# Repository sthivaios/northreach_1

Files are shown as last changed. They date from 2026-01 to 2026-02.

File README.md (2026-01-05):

# NorthReach 1

## Introduction

NorthReach 1 is a wired USB remote controller, to aid during presentations, particularly
on touchscreen interactive whiteboards.

Apart from basic features that other commercially available presenter remotes have, NorthReach
includes buttons for controlling Windows computers by default, such as a separate button for closing
the focused window, or a button to bring up Task Manager in the event that some application freezes.

The firmware is written in C, with the Espressif ESP-IDF framework. Through the `menuconfig` utility,
the board can be reconfigured to assign different actions to any button, for example to make the remote
compatible with MacOS.

Additionally, under the `hardware/` directory, the KiCad project for the PCB is available, as well
as the 3D printed enclosure inside `enclosure/`.

**The firmware and the PCB is only designed for ESP-S3 modules which natively support USB.**

In the future, there will also be a wireless version of NorthReach, possibly based on a Nordic nRF SoC.
However, for now, I'm focusing on the wired version.

## Contributing

You are more than welcome to contribute to the project, by forking then creating a pull request.
If you are an end user, feel free to request new features or report a bug by creating an issue
on this repository on GitHub.

If you are actually contributing code to the project, make sure that you understand the license terms.

## Licensing
This project contains multiple components under different licenses.
See [LICENSE](LICENSE) for more details.

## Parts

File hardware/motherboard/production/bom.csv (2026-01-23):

Designator | Footprint | Quantity | Value | LCSC Part #
C1 | 0805 | 1 | 1uF | C28323
C2, C5 | 0805 | 2 | 10uF | C15850
C3, C4 | 0805 | 2 | 0.1uF | C28233
J1 | USB_C_Receptacle_Amphenol_12401610E4-2A | 1 | USB_C_Receptacle | C5119948
J2, J4 | PinHeader_1x03_P2.54mm_Vertical | 2 | Conn_01x03_Pin
J3 | Hirose_FH12-20S-0.5SH_1x20-1MP_P0.50mm_Horizontal | 1 | Conn_01x20 | C596730
R1, R2 | 0805 | 2 | 5.1k | C84375
R3, R4 | 0805 | 2 | 10k | C84376
SW1, SW2 | SW_PUSH_6mm_H4.3mm | 2 | SW_Push
U1 | Texas_RGW0020A_VQFN-20-1EP_5x5mm_P0.65mm_EP3.15x3.15mm_ThermalVias | 1 | TPS7A4701xRGW | C90084
U2 | ESP32-S2-MINI-1U | 1 | ESP32-S3-MINI-1U | C2980299
U3 | SOT-23-6 | 1 | USBLC6-2SC6 | C7519

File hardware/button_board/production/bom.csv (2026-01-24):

Designator | Footprint | Quantity | Value | LCSC Part #
J1 | Hirose_FH12-20S-0.5SH_1x20-1MP_P0.50mm_Horizontal | 1 | Conn_01x20
SW1 | SW_BUTTON_SoftTactile | 1 | Left
SW10 | SW_BUTTON_SoftTactile | 1 | Vol_Up
SW11 | SW_BUTTON_SoftTactile | 1 | Vol_Down
SW2 | SW_BUTTON_SoftTactile | 1 | Right
SW3 | SW_BUTTON_SoftTactile | 1 | Up
SW4 | SW_BUTTON_SoftTactile | 1 | Down
SW5 | SW_BUTTON_SoftTactile | 1 | Return
SW6 | SW_BUTTON_SoftTactile | 1 | Fn_1
SW7 | SW_BUTTON_SoftTactile | 1 | Fn_2
SW8 | SW_BUTTON_SoftTactile | 1 | Fn_3
SW9 | SW_BUTTON_SoftTactile | 1 | Fn_4

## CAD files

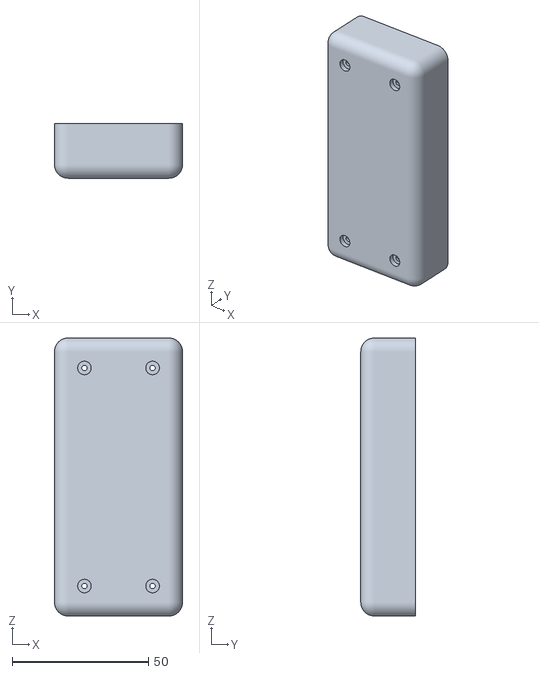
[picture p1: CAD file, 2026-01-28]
enclosure/v4/exports/northreach_1_v4_NorthReach 1 v23_MainBody_1_MainBody.stl
47.0 x 20.0 x 102.0

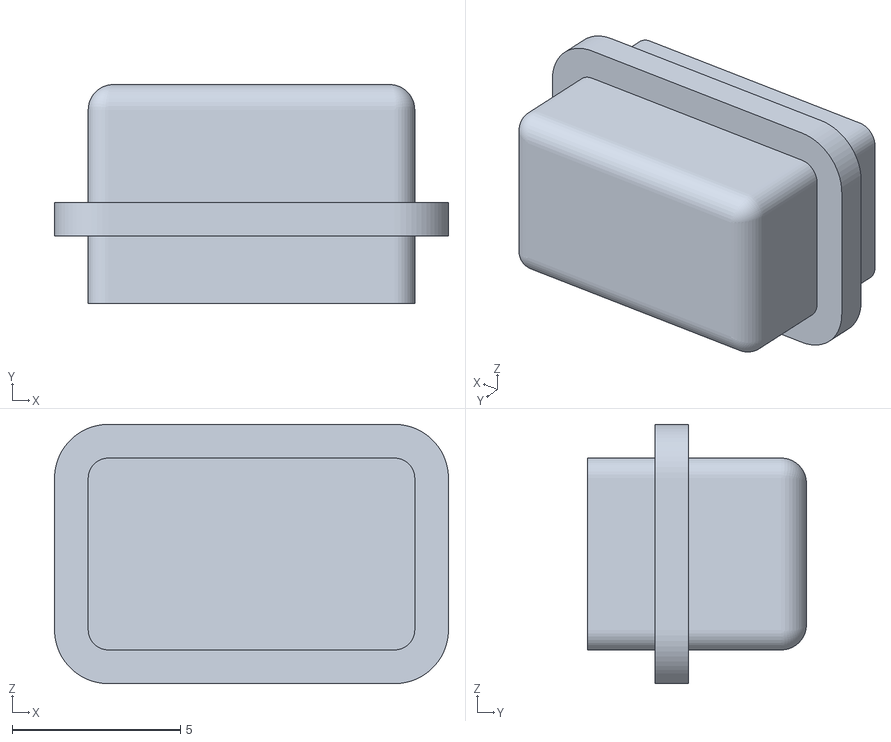
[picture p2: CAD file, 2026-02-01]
enclosure/v4/exports/rectangle_button_single.stl
11.7 x 6.50 x 7.70

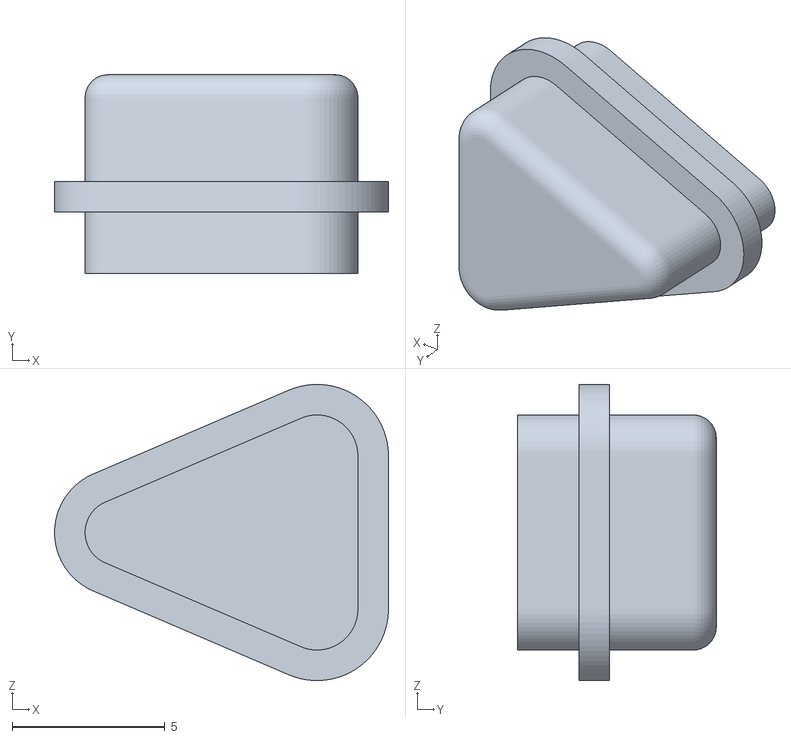
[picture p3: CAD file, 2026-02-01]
enclosure/v4/exports/triangle_button_single.stl
10.9 x 6.50 x 9.69

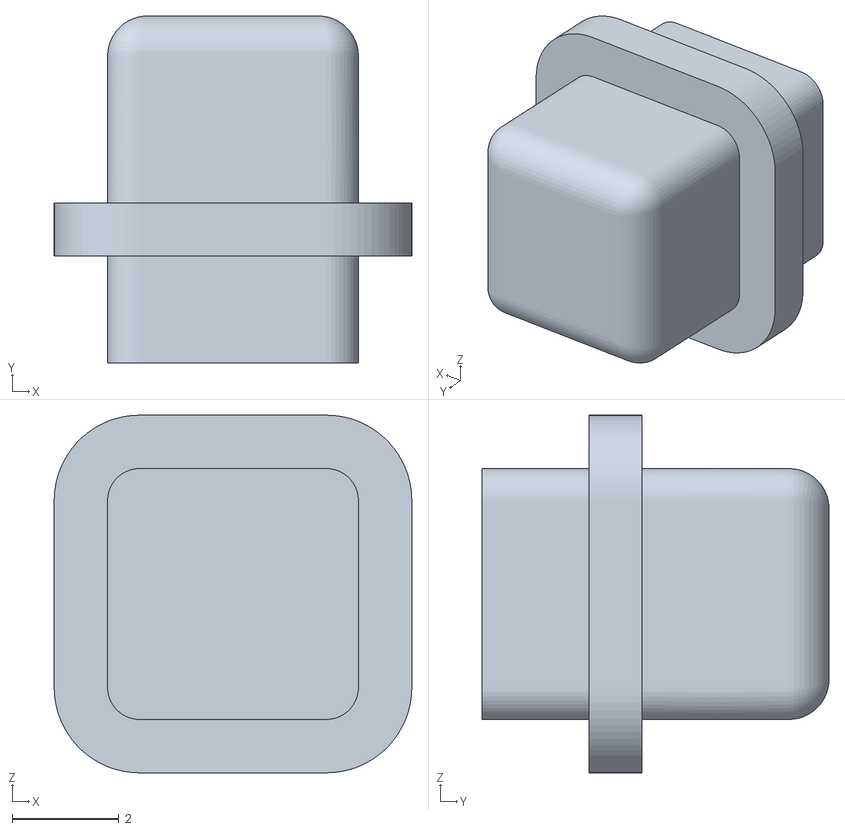
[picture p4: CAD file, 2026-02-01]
enclosure/v4/exports/square_button_single.stl
6.70 x 6.50 x 6.70

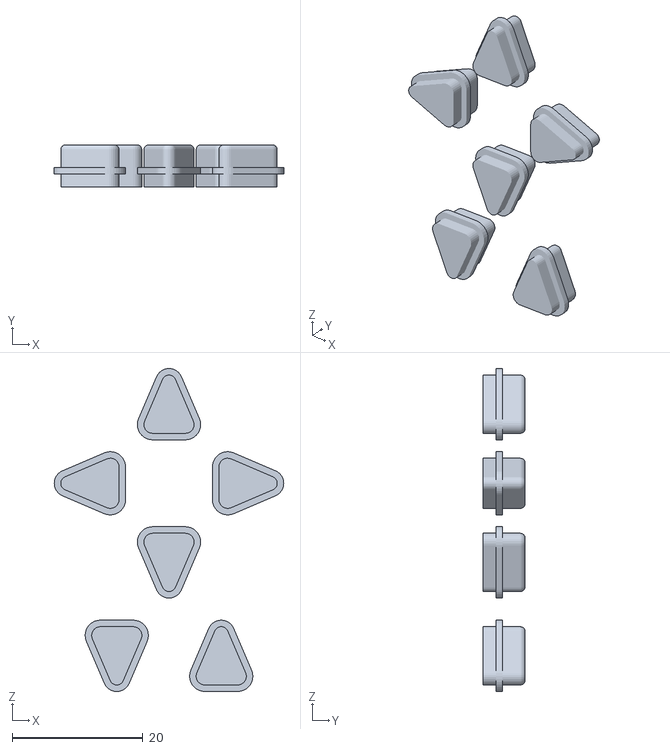
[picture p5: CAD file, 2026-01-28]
enclosure/v4/exports/northreach_1_v4_NorthReach 1 v23_Buttons_1_TriangleButton_1_TriangleButton.stl
35.2 x 6.50 x 49.5

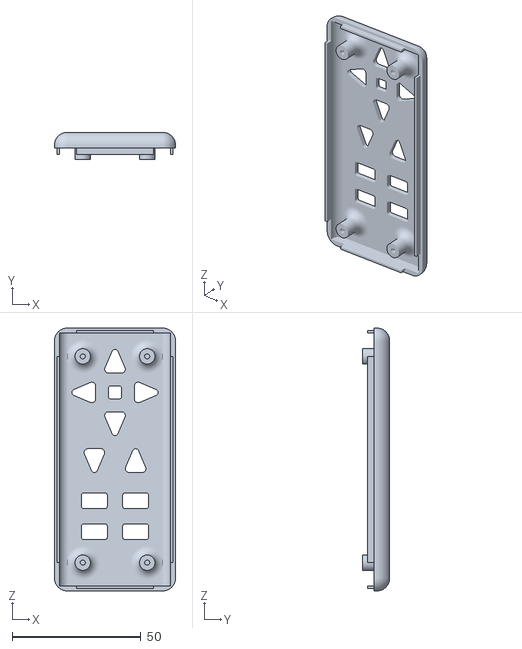
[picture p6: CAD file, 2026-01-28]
enclosure/v4/exports/northreach_1_v4_NorthReach 1 v23_TopCover_1_TopCover.stl
47.0 x 10.6 x 102.0

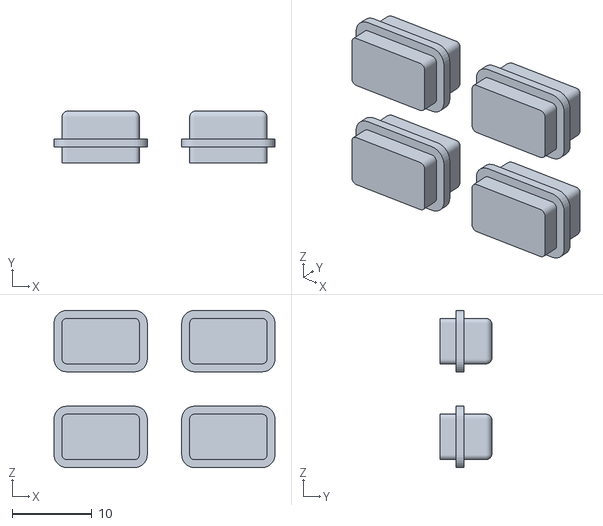
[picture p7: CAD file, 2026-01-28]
enclosure/v4/exports/northreach_1_v4_NorthReach 1 v23_Buttons_1_RectangleButton_1_RectangleButton.stl
27.7 x 6.50 x 19.7

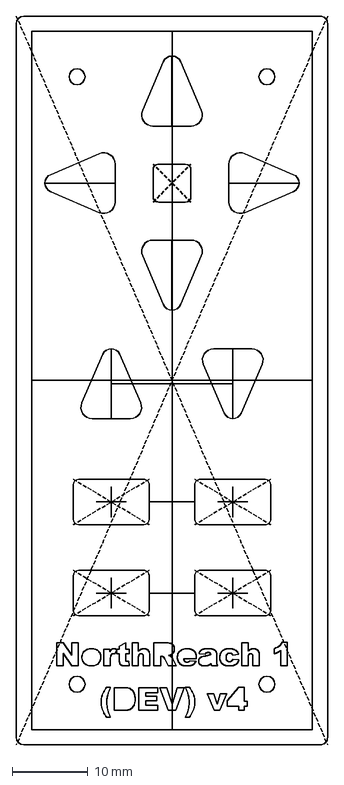
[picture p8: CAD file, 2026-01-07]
enclosure/v4/exports/KiCad_PCB_Reference.dxf
41.0 x 96.0 mm

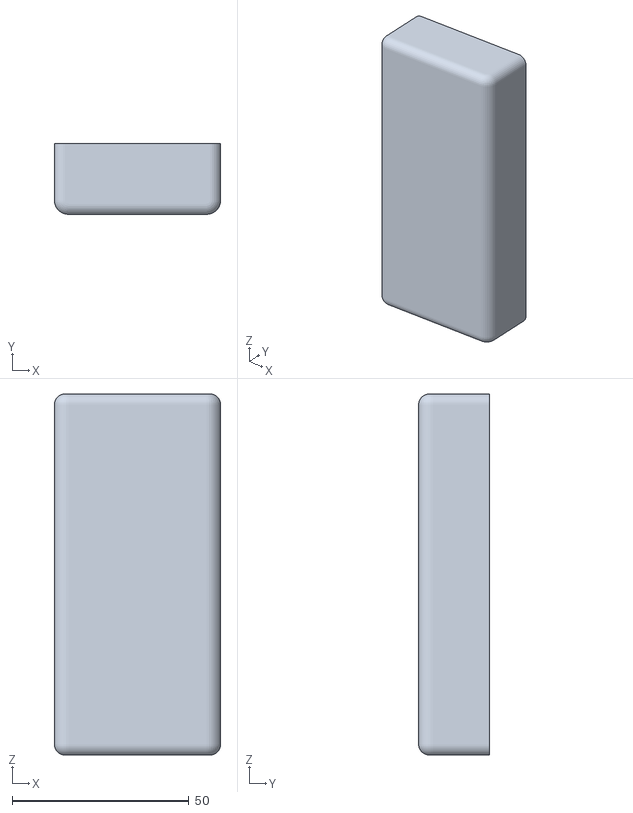
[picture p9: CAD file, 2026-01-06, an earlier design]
enclosure/v1/exports/northreach_1_v1_main-body.stl
47.0 x 20.0 x 102.0

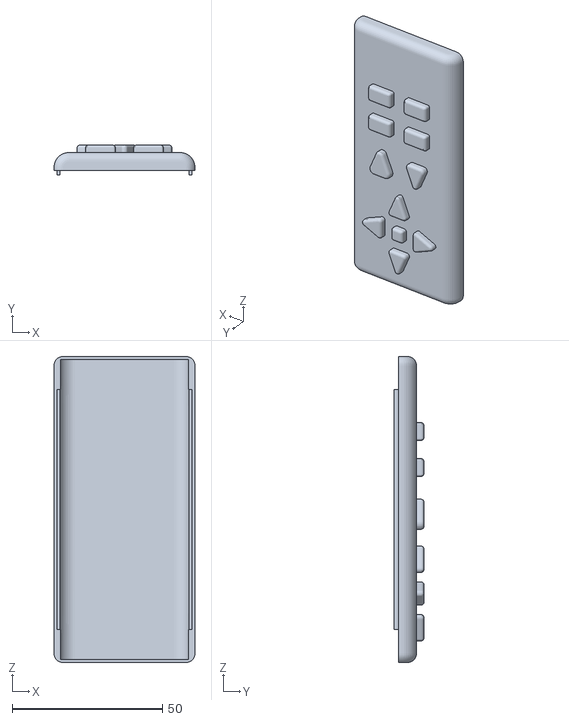
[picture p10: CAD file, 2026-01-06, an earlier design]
enclosure/v1/exports/northreach_1_v1_top-cover.stl
47.0 x 10.0 x 102.0

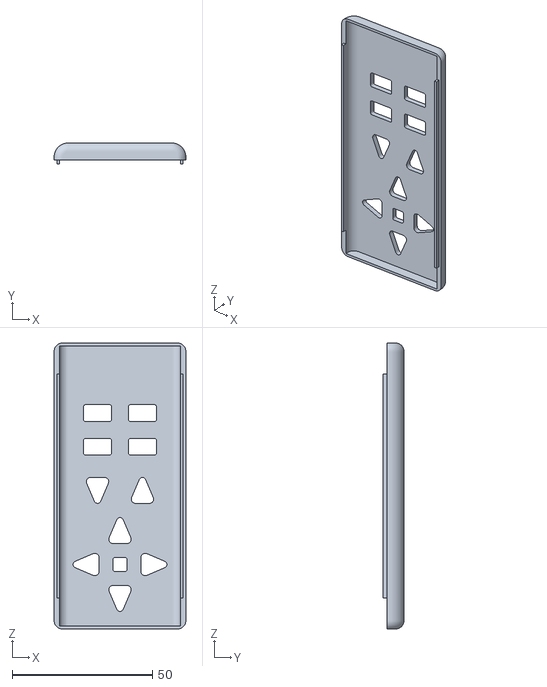
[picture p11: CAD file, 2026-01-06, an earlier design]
enclosure/v2/exports/northreach_1_v2_TopCover.stl
47.0 x 7.50 x 102.0

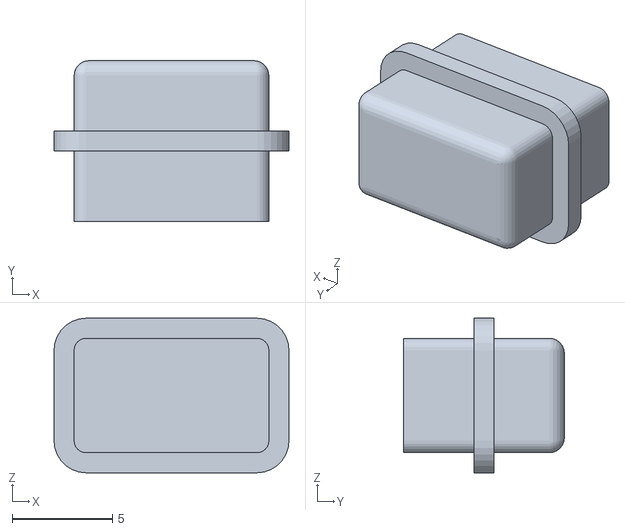
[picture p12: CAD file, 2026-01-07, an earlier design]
enclosure/v3/exports/northreach_1_v3_NorthReach 1 v11_RectangleButton_3_RectangleButton.stl
11.7 x 8.00 x 7.70

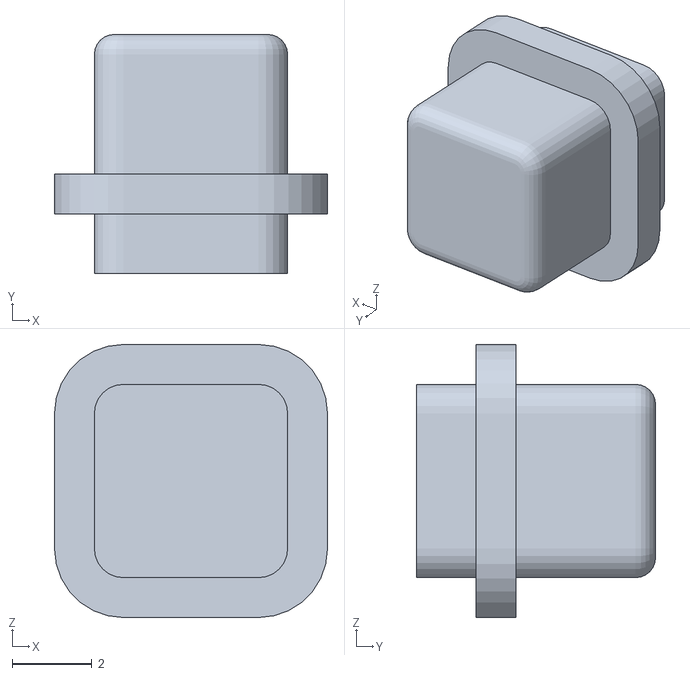
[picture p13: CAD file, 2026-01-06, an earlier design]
enclosure/v2/exports/northreach_1_v2_SquareButton.stl
6.85 x 6.00 x 6.85

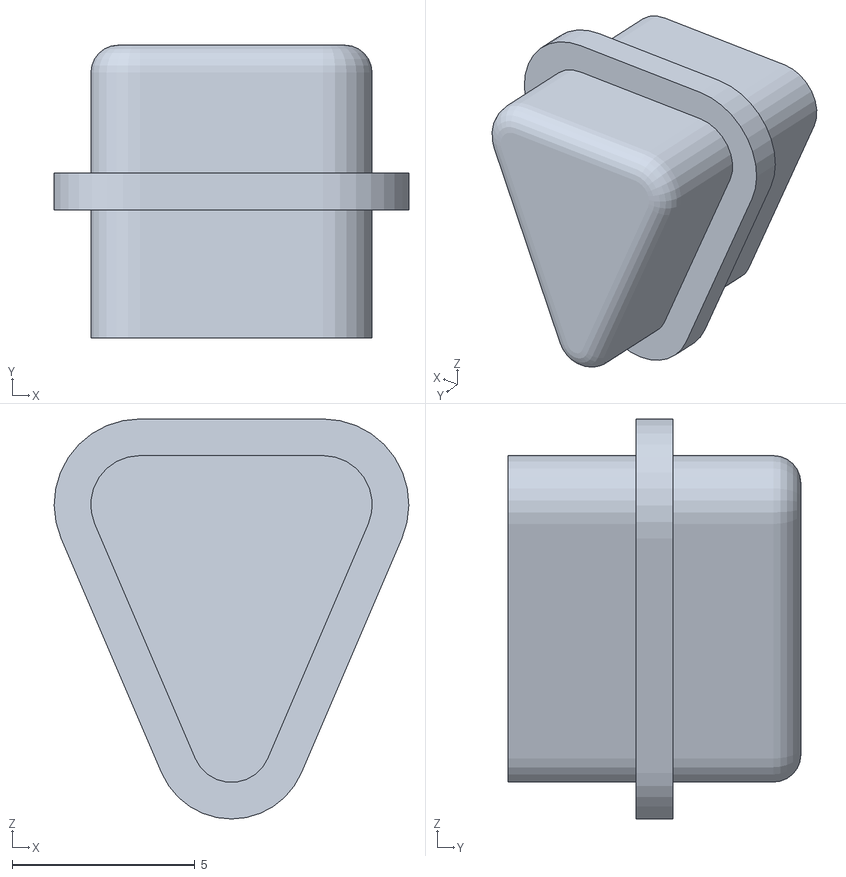
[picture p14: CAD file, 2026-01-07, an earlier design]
enclosure/v3/exports/northreach_1_v3_NorthReach 1 v11_TriangleButton_4_TriangleButton.stl
9.69 x 8.00 x 10.9

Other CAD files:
enclosure/v4/exports/northreach_1_v4_NorthReach 1 v23_Buttons_1_SquareButton_1_SquareButton.stl
enclosure/v2/exports/northreach_1_v2_MainBody.stl
enclosure/v3/exports/northreach_1_v3_NorthReach 1 v11_MainBody_1_MainBody.stl
enclosure/v2/exports/northreach_1_v2_RectangleButton.stl
enclosure/v1/northreach_1_v1.f3d
enclosure/v2/exports/northreach_1_v2_TriangleButton.stl
enclosure/v2/northreach_1_v2.f3d
enclosure/v3/exports/northreach_1_v3_NorthReach 1 v11_RectangleButton_1_RectangleButton.stl
enclosure/v3/exports/northreach_1_v3_NorthReach 1 v11_RectangleButton_2_RectangleButton.stl
enclosure/v3/exports/northreach_1_v3_NorthReach 1 v11_RectangleButton_4_RectangleButton.stl
enclosure/v3/exports/northreach_1_v3_NorthReach 1 v11_SquareButton_1_SquareButton.stl
enclosure/v3/exports/northreach_1_v3_NorthReach 1 v11_TopCover_1_TopCover.stl
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

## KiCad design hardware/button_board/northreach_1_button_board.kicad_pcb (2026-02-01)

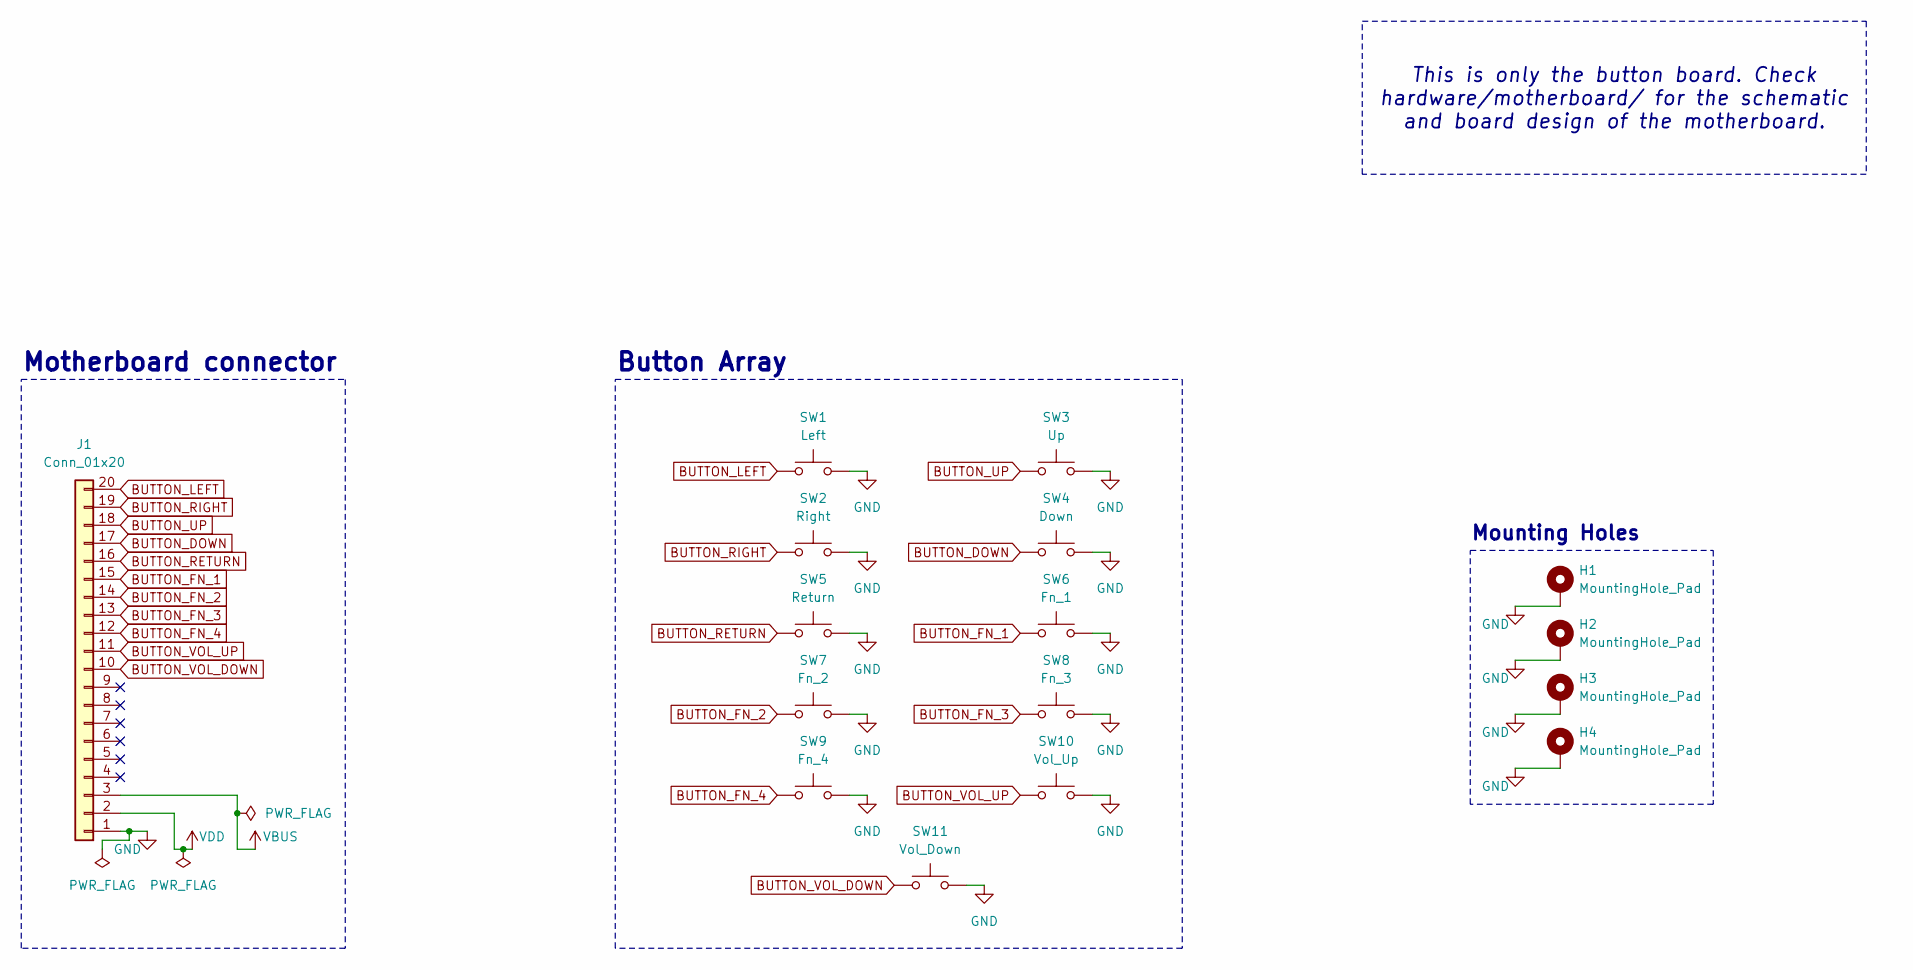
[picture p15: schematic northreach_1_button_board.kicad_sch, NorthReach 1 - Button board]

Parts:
H1, H2, H3, H4: MountingHole_Pad; MountingHole_2.2mm_M2_Pad
J1: Conn_01x20; Hirose_FH12-20S-0.5SH_1x20-1MP_P0.50mm_Horizontal; LCSC C596730
SW1: Left; SW_BUTTON_SoftTactile
SW2: Right; SW_BUTTON_SoftTactile
SW3: Up; SW_BUTTON_SoftTactile
SW4: Down; SW_BUTTON_SoftTactile
SW5: Return; SW_BUTTON_SoftTactile
SW6: Fn_1; SW_BUTTON_SoftTactile
SW7: Fn_2; SW_BUTTON_SoftTactile
SW8: Fn_3; SW_BUTTON_SoftTactile
SW9: Fn_4; SW_BUTTON_SoftTactile
SW10: Vol_Up; SW_BUTTON_SoftTactile
SW11: Vol_Down; SW_BUTTON_SoftTactile

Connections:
BUTTON_DOWN: J1.17, SW4.1
BUTTON_FN_1: J1.15, SW6.1
BUTTON_FN_2: J1.14, SW7.1
BUTTON_FN_3: J1.13, SW8.1
BUTTON_FN_4: J1.12, SW9.1
BUTTON_LEFT: J1.20, SW1.1
BUTTON_RETURN: J1.16, SW5.1
BUTTON_RIGHT: J1.19, SW2.1
BUTTON_UP: J1.18, SW3.1
BUTTON_VOL_DOWN: J1.10, SW11.1
BUTTON_VOL_UP: J1.11, SW10.1
GND: H1.1, H2.1, H3.1, H4.1, J1.1, SW1.2, SW2.2, SW3.2, SW4.2, SW5.2, SW6.2, SW7.2, SW8.2, SW9.2, SW10.2, SW11.2
VBUS: J1.3
VDD: J1.2

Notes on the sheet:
Motherboard connector
Mounting Holes
Button Array
This is only the button board. Check hardware/motherboard/ for the schematic and board design of the motherboard.

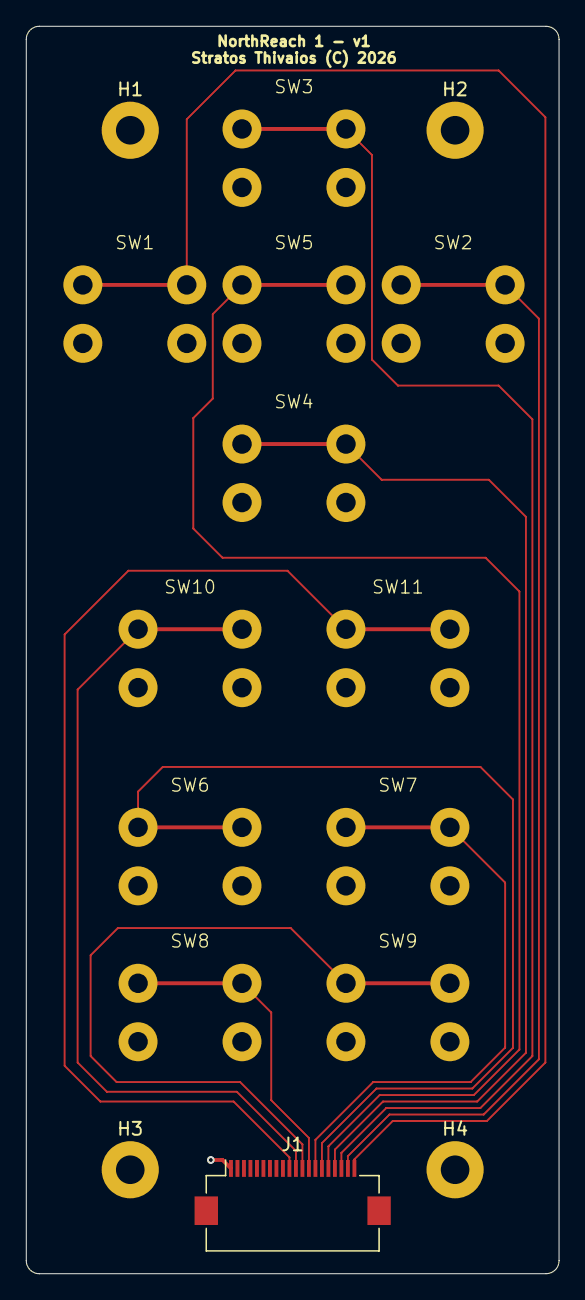
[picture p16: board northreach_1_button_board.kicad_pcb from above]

Board: 2 copper layers, 41.0 x 96.0 mm, 16 parts (0 on the bottom side), 12 nets.

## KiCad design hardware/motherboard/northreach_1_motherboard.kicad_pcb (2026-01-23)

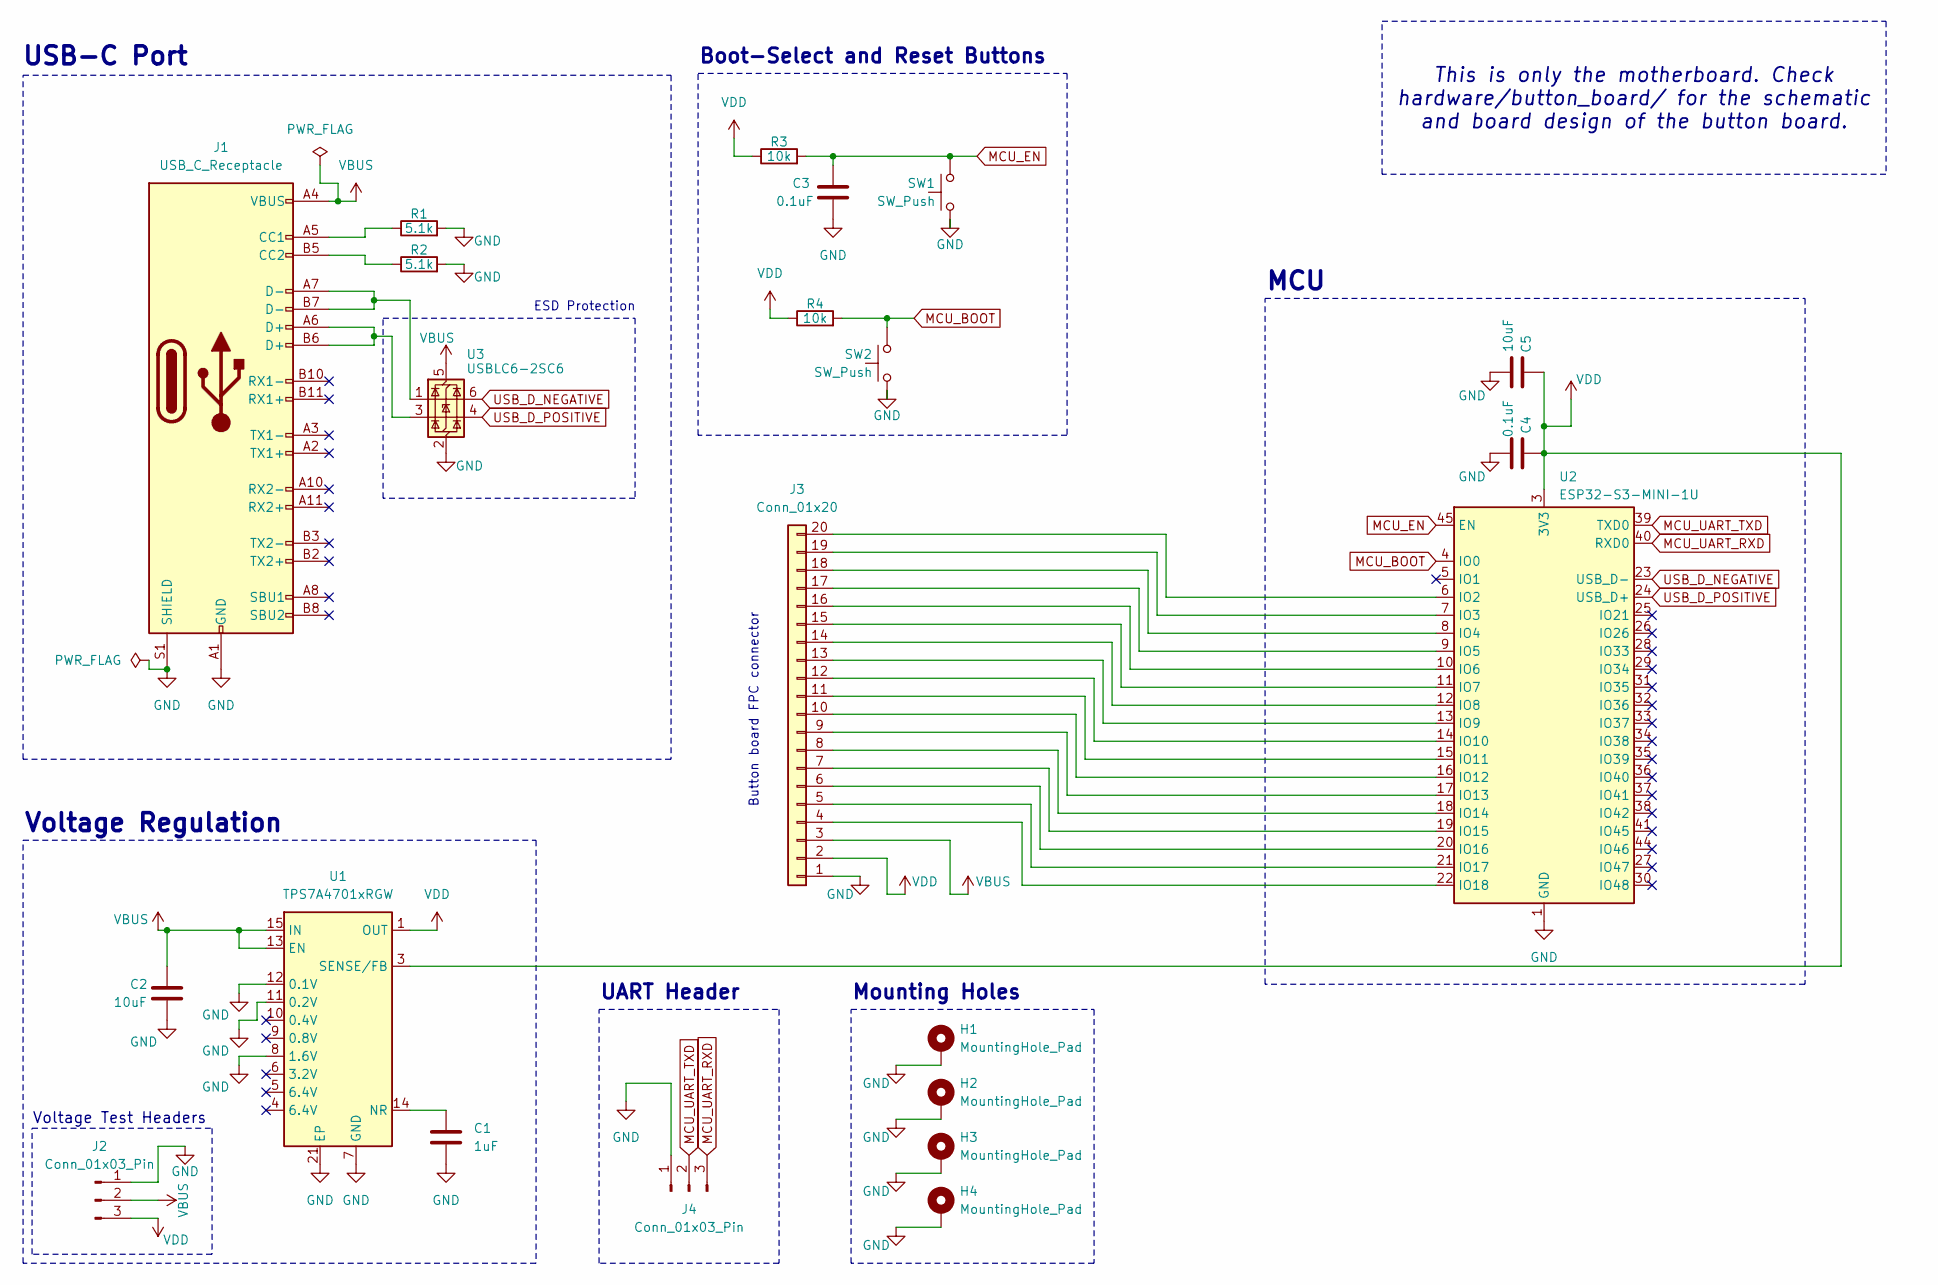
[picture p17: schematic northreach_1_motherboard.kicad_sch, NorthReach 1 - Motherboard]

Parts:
C1: 1uF; C_0805_2012Metric; LCSC C28323
C2, C5: 10uF; C_0805_2012Metric; LCSC C15850
C3, C4: 0.1uF; C_0805_2012Metric; LCSC C28233
H1, H2, H3, H4: MountingHole_Pad; MountingHole_2.2mm_M2_Pad
J1: USB_C_Receptacle; USB_C_Receptacle_Amphenol_12401610E4-2A; LCSC C5119948
J2, J4: Conn_01x03_Pin; PinHeader_1x03_P2.54mm_Vertical
J3: Conn_01x20; Hirose_FH12-20S-0.5SH_1x20-1MP_P0.50mm_Horizontal; LCSC C596730
R1, R2: 5.1k; R_0805_2012Metric; LCSC C84375
R3, R4: 10k; R_0805_2012Metric; LCSC C84376
SW1, SW2: SW_Push; SW_PUSH_6mm_H4.3mm
U1: TPS7A4701xRGW; Texas_RGW0020A_VQFN-20-1EP_5x5mm_P0.65mm_EP3.15x3.15mm_Ther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; LCSC C90084
U2: ESP32-S3-MINI-1U; ESP32-S2-MINI-1U; LCSC C2980299
U3: USBLC6-2SC6; SOT-23-6; LCSC C7519

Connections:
GND: C1.1, C2.1, C3.1, C4.1, C5.1, H1.1, H2.1, H3.1, H4.1, J1.A1 (GND), J1.A12 (GND), J1.B1 (GND), J1.B12 (GND), J1.S1 (SHIELD), J2.1, J3.1, J4.1, R1.2, R2.2, SW1.1, SW2.1, U1.7 (GND), U1.8 (1.6V), U1.11 (0.2V), U1.12 (0.1V), U1.21 (EP), U2.1 (GND), U2.2 (GND), U2.42 (GND), U2.43 (GND), U2.46 (GND), U2.47 (GND), U2.48 (GND), U2.49 (GND), U2.50 (GND), U2.51 (GND), U2.52 (GND), U2.53 (GND), U2.54 (GND), U2.55 (GND), U2.56 (GND), U2.57 (GND), U2.58 (GND), U2.59 (GND), U2.60 (GND), U2.61 (GND), U2.62 (GND), U2.63 (GND), U2.64 (GND), U2.65 (GND), U3.2 (GND)
MCU_BOOT: R4.2, SW2.2, U2.4 (IO0)
MCU_EN: C3.2, R3.2, SW1.2, U2.45 (EN)
MCU_UART_RXD: J4.3, U2.40 (RXD0)
MCU_UART_TXD: J4.2, U2.39 (TXD0)
unnamed: J1.A5 (CC1), R1.1
unnamed: J1.B5 (CC2), R2.1
unnamed: J1.A6 (D+), J1.B6 (D+), U3.3 (I/O2)
unnamed: J1.A7 (D-), J1.B7 (D-), U3.1 (I/O1)
unnamed: J3.4, U2.22 (IO18)
unnamed: J3.5, U2.21 (IO17)
unnamed: J3.6, U2.20 (IO16)
unnamed: J3.7, U2.19 (IO15)
unnamed: J3.8, U2.18 (IO14)
unnamed: J3.9, U2.17 (IO13)
unnamed: J3.10, U2.16 (IO12)
unnamed: J3.11, U2.15 (IO11)
unnamed: J3.12, U2.14 (IO10)
unnamed: J3.13, U2.13 (IO9)
unnamed: J3.14, U2.12 (IO8)
unnamed: J3.15, U2.11 (IO7)
unnamed: J3.16, U2.10 (IO6)
unnamed: J3.17, U2.9 (IO5)
unnamed: J3.18, U2.8 (IO4)
unnamed: J3.19, U2.7 (IO3)
unnamed: J3.20, U2.6 (IO2)
unnamed: C1.2, U1.14 (NR)
USB_D_NEGATIVE: U2.23 (USB_D-), U3.6 (I/O1)
USB_D_POSITIVE: U2.24 (USB_D+), U3.4 (I/O2)
VBUS: C2.2, J1.A4 (VBUS), J1.A9 (VBUS), J1.B4 (VBUS), J1.B9 (VBUS), J2.2, J3.3, U1.13 (EN), U1.15 (IN), U1.16 (IN), U3.5 (VBUS)
VDD: C4.2, C5.2, J2.3, J3.2, R3.1, R4.1, U1.1 (OUT), U1.3 (SENSE/FB), U1.20 (OUT), U2.3 (3V3)

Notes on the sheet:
Voltage Regulation
Voltage Test Headers
Mounting Holes
UART Header
Boot-Select and Reset Buttons
Button board FPC connector
MCU
ESD Protection
USB-C Port
This is only the motherboard. Check hardware/button_board/ for the schematic and board design of the button board.

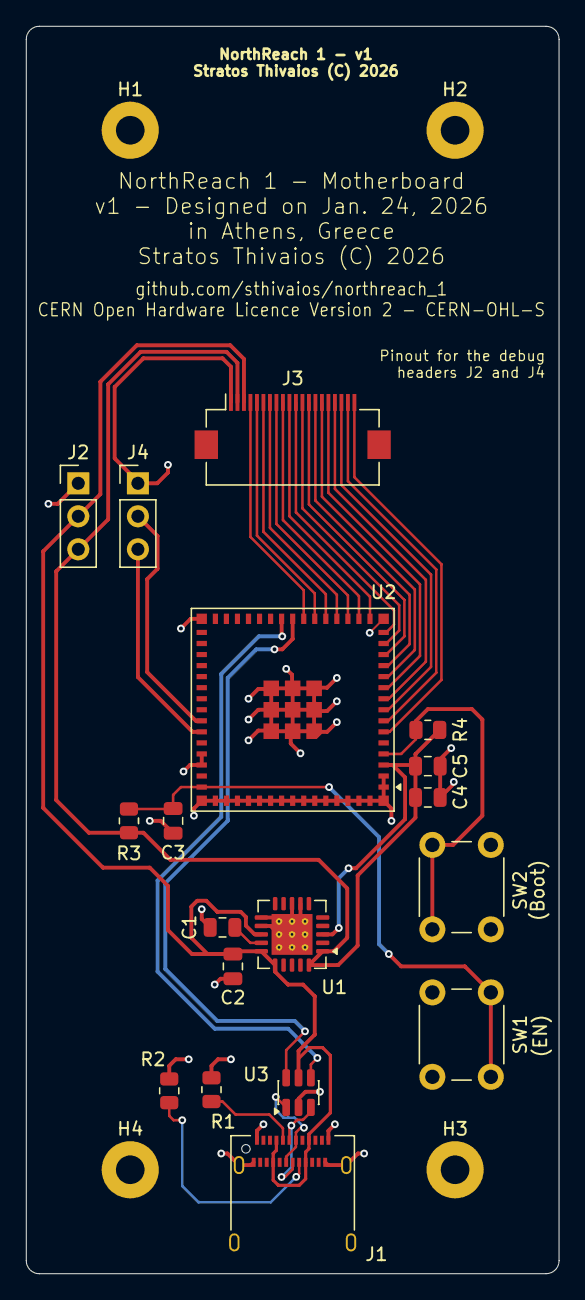
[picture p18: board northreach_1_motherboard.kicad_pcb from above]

Board: 2 copper layers, 41.0 x 96.0 mm, 22 parts (0 on the bottom side), 31 nets.

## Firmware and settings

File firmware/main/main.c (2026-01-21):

// Copyright 2026 Stratos Thivaios
//
// Licensed under the Apache License, Version 2.0 (the "License");
// you may not use this file except in compliance with the License.
// You may obtain a copy of the License at
//
//     http://www.apache.org/licenses/LICENSE-2.0
//
// Unless required by applicable law or agreed to in writing, software
// distributed under the License is distributed on an "AS IS" BASIS,
// WITHOUT WARRANTIES OR CONDITIONS OF ANY KIND, either express or implied.
// See the License for the specific language governing permissions and
// limitations under the License.

#include "buttons.h"
#include "hid.h"

#include <task.h>

void app_main(void) {

  xTaskCreate(buttonTask, "button_task", 8192, NULL, 10, NULL);
  xTaskCreate(hid_task, "hid_task", 8192, NULL, 5, NULL);
}

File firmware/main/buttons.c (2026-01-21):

// Copyright 2026 Stratos Thivaios
//
// Licensed under the Apache License, Version 2.0 (the "License");
// you may not use this file except in compliance with the License.
// You may obtain a copy of the License at
//
//     http://www.apache.org/licenses/LICENSE-2.0
//
// Unless required by applicable law or agreed to in writing, software
// distributed under the License is distributed on an "AS IS" BASIS,
// WITHOUT WARRANTIES OR CONDITIONS OF ANY KIND, either express or implied.
// See the License for the specific language governing permissions and
// limitations under the License.

#include "buttons.h"

#include "freertos/FreeRTOS.h"
#include "freertos/queue.h"

#include "button_gpio.h"
#include "button_types.h"
#include "esp_log.h"
#include "iot_button.h"

static const char *TAG = "button_task";

QueueHandle_t xButtonEventQueue;
static button_handle_t button_handles_array[11];

// disgusting stupid array for getting a string from the enums to print to the
// log
static const char *button_names[11] = {
    [BTN_UP] = "UP",
    [BTN_DOWN] = "DOWN",
    [BTN_LEFT] = "LEFT",
    [BTN_RIGHT] = "RIGHT",
    [BTN_ENTER] = "ENTER",
    [BTN_VOL_UP] = "VOL_UP",
    [BTN_VOL_DOWN] = "VOL_DOWN",
    [BTN_F1] = "F1",
    [BTN_F2] = "F2",
    [BTN_F3] = "F3",
    [BTN_F4] = "F4",
};

BaseType_t xButtonQueueReceive(button_id_enum *ButtonID,
                               const TickType_t xTicksToWait) {
  if (!xButtonEventQueue || ButtonID == NULL) {
    return pdFAIL;
  }
  return xQueueReceive(xButtonEventQueue, ButtonID, xTicksToWait);
}

BaseType_t xButtonQueueSend(button_id_enum ButtonID,
                            const TickType_t xTicksToWait) {
  if (!xButtonEventQueue) {
    return pdFAIL;
  }
  return xQueueSend(xButtonEventQueue, &ButtonID, xTicksToWait);
}

void button_single_click_cb(void *arg, void *usr_data) {
  const button_id_enum btn_id = (button_id_enum)(intptr_t)usr_data;
  ESP_LOGI(TAG, "Click event from button: %s", button_names[btn_id]);
  xButtonQueueSend(btn_id, portMAX_DELAY);
}

void buttons_init() {

  int i_pin = 2;
  int i_array = 0;

  while (i_pin <= 12) {
    const button_config_t btn_cfg = {0};
    const button_gpio_config_t btn_gpio_cfg = {
        .gpio_num = i_pin,
        .active_level = 0,
    };
    button_handle_t gpio_btn = NULL;
    ESP_ERROR_CHECK(
        iot_button_new_gpio_device(&btn_cfg, &btn_gpio_cfg, &gpio_btn));
    if (NULL == gpio_btn) {
      ESP_LOGE(TAG, "Button [ %d ] create failed", i_pin);
      abort();
    }

    button_handles_array[i_array] = gpio_btn;

    ESP_LOGI(TAG, "Button [ %d ] configured", i_pin);

    i_pin++;
    i_array++;
  }

  const button_id_enum btn_ids[] = {
      BTN_LEFT, BTN_RIGHT, BTN_UP, BTN_DOWN,   BTN_ENTER,   BTN_F1,
      BTN_F2,   BTN_F3,    BTN_F4, BTN_VOL_UP, BTN_VOL_DOWN};

  for (int i = 0; i <= 10; i++) {
    ESP_LOGI(TAG, "Registering: Button array index: %d - %s", i,
             button_names[btn_ids[i]]);
    if (i <= 4 || i >= 9) {
      ESP_ERROR_CHECK(iot_button_register_cb(
          button_handles_array[i], BUTTON_PRESS_DOWN, NULL,
          button_single_click_cb, (void *)(intptr_t)btn_ids[i]));
      ESP_ERROR_CHECK(iot_button_register_cb(
          button_handles_array[i], BUTTON_LONG_PRESS_HOLD, NULL,
          button_single_click_cb, (void *)(intptr_t)btn_ids[i]));
      // ESP_LOGI(TAG, "Registered callbacks for button [ %d ]", i);
    } else {
      ESP_ERROR_CHECK(iot_button_register_cb(
          button_handles_array[i], BUTTON_LONG_PRESS_START, NULL,
          button_single_click_cb, (void *)(intptr_t)btn_ids[i]));
      // ESP_LOGI(TAG, "Registered long press callbacks for button [ %d ]", i);
    }
  }
}

void buttonTask(void *pvParameters) {

  buttons_init();

  xButtonEventQueue = xQueueCreate(50, sizeof(button_id_enum));
  if (xButtonEventQueue == NULL) {
    ESP_LOGE(TAG, "The button event queue was not created successfully! This "
                  "is a fatal error. Aborting!");
    abort();
  }

  ESP_LOGW(TAG, "Buttons configured successfully in the button task. The task "
                "will now self delete.");
  vTaskDelete(NULL);
}

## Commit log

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2026-01-06 schematic: usb-c port section
    [northreach_1.kicad_sch]
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2026-01-06 schematic: add voltage regulator
    [northreach_1.kicad_sch]
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2026-01-06 enclosure: stl exports of v1
    [northreach_1_v1_main-body.stl, northreach_1_v1_top-cover.stl]
2026-01-06 enclosure: v1 - update fillets and stuff
    [northreach_1_v1.f3d, northreach_1_v1_main-body.stl, northreach_1_v1_top-cover.stl]
2026-01-06 enclosure: v2 - separate buttons
    [northreach_1_v2.f3d, northreach_1_v2_MainBody.stl, northreach_1_v2_RectangleButton.stl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]
2026-01-06 schematic: add MCU, and bootselect and reset buttons
    [northreach_1.kicad_sch]
2026-01-06 schematic: MCU UART header
    [northreach_1.kicad_sch]
2026-01-06 schematic: reorganize it a little
    [northreach_1.kicad_sch]
2026-01-06 schematic: add button array and status led
    [northreach_1.kicad_sch]
2026-01-06 schematic: J4 was missing a footprint
    [northreach_1.kicad_sch]
2026-01-07 enclosure: clean new fusion project with components
    [northreach_1_v3.f3d, northreach_1_v3_NorthReach 1 v11_MainBody_1_MainBody.stl, northreach_1_v3_NorthReach 1 v11_RectangleButton_1_RectangleButton.stl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]
2026-01-07 enclosure: v4: added standoffs
    [northreach_1_v4.f3d, northreach_1_v4_NorthReach 1 v16_Buttons_1_RectangleButton_1_RectangleButton.stl, northreach_1_v4_NorthReach 1 v16_Buttons_1_SquareButton_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]
2026-01-07 schematic: add M2 mounting holes (grounded)
    [northreach_1.kicad_sch]
2026-01-07 enclosure: add kicad reference sketch and export as dfx
    [KiCad_PCB_Reference.dxf, northreach_1_v4.f3d]
2026-01-07 chore: separate schematics and stuff to two boards
    [northreach_1_button_board.kicad_pcb, northreach_1_button_board.kicad_sch]
2026-01-08 schematic: separate boards, add FPC connector
    [northreach_1_button_board.kicad_sch, northreach_1_motherboard.kicad_pcb, northreach_1_motherboard.kicad_sch]
2026-01-08 schematic: update connector name lol
    [northreach_1_button_board.kicad_sch]
2026-01-08 pcb: button board: layout
    [northreach_1_button_board.kicad_pcb]
2026-01-08 pcb: button board: routing
    [northreach_1_button_board.kicad_pcb]
2026-01-08 pcb: button board: GND plane clearances
    [northreach_1_button_board.kicad_pcb]
2026-01-08 pcb: button board: labels and copyright lol
    [northreach_1_button_board.kicad_pcb]
2026-01-08 pcb: button board: add LCSC codes, generate production files
    [bom.csv, designators.csv, northreach_1_button_board.kicad_sch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]
2026-01-08 schematic_and_pcb: button board: remove led for now
    [northreach_1_button_board.kicad_pcb, northreach_1_button_board.kicad_sch]
2026-01-08 pcb: button board: regenerate production files
    [bom.csv, designators.csv, positions.csv]
2026-01-08 enclosure: minor changes, export new STLs
    [northreach_1_v4.f3d, northreach_1_v4_Buttons_1_RectangleButtons.stl, northreach_1_v4_Buttons_1_SquareButtons.stl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]
2026-01-09 chore: not entirely sure what the heck just changed but im committing it
    [northreach_1_button_board.kicad_pcb]
2026-01-10 kicad: add LCSC parts
    [northreach_1_motherboard.kicad_sch]
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2026-01-21 firmware: buttons.c: error handling, array-based button config, rename some stuff, add better logging
    [buttons.c]
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2026-01-21 schematic: motherboard: change switch footprint for EN and RESET
    [northreach_1_motherboard.kicad_sch]
2026-01-21 pcb: button board: place components
    [northreach_1_motherboard.kicad_pcb]
2026-01-21 pcb: motherboard: route stuff
    [northreach_1_motherboard.kicad_pcb]
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2026-01-22 pcb: button board: silkscreen
    [northreach_1_button_board.kicad_pcb]
2026-01-22 pcb: generate prod files
    [bom.csv, designators.csv, positions.csv]
2026-01-23 schematic: motherboard: add usb esd protection
    [northreach_1_motherboard.kicad_sch]
2026-01-23 pcb: motherboard: add ESD protection
    [northreach_1_motherboard.kicad_pcb]
2026-01-23 pcb: motherboard: fix silkscreen stuff
    [northreach_1_motherboard.kicad_pcb]
2026-01-23 schematic: motherboard: text, drawing sheet details
    [northreach_1_motherboard.kicad_sch]
2026-01-23 schematic_and_pcb: button board: SW numbering
    [northreach_1_button_board.kicad_pcb, northreach_1_button_board.kicad_sch]
2026-01-23 pcb: motherboard: rev v2.0 generate prod files
    [bom.csv, designators.csv, northreach_1_motherboard.kicad_pcb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]
2026-01-23 pcb: button_board: rev v1.1 generate prod files
    [bom.csv, designators.csv, northreach_1_button_board.kicad_pcb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]
2026-01-23 schematic_and_pcb: motherboard: route SENSE VREG pin to load
    [northreach_1_motherboard.kicad_pcb, northreach_1_motherboard.kicad_sch]
2026-01-23 schematic_and_pcb: motherboard: add ESD protection IC LCSC id
    [northreach_1_motherboard.kicad_pcb, northreach_1_motherboard.kicad_sch]
2026-01-23 pcb: motherboard: rev v2.1 generate prod files
    [bom.csv]
2026-01-23 pcb: button_board: move J1 up
    [northreach_1_button_board.kicad_pcb]
2026-01-23 pcb: button_board: rev v1.2 generate prod files
    [northreach_1_motherboard.kicad_pcb, positions.csv]
2026-01-23 pcb: button_board: move silkscreen, regenerate prod files
    [northreach_1_button_board.kicad_pcb]
2026-01-23 pcb: motherboard: move silkscreen, regenerate prod files
    [northreach_1_motherboard.kicad_pcb]
2026-01-24 pcb: motherboard: proper footprint for buttons
    [northreach_1_button_board.kicad_pcb, northreach_1_button_board.kicad_sch]
2026-01-24 pcb: button_board: rev v1.3 generate prod files
    [bom.csv, northreach_1_button_board.kicad_pcb, positions.csv]
2026-01-24 pcb: button_board: footprint pins were wrong for the SWs
2026-01-24 pcb: button_board: footprint pins were still wrong for the SWs lmao
2026-01-24 pcb: button_board: reroute buttons since the footprint was wrong
    [northreach_1_button_board.kicad_pcb]
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2026-01-28 enclosure: shorten button height
    [northreach_1_v4.f3d, northreach_1_v4_Buttons_1_RectangleButtons.stl, northreach_1_v4_Buttons_1_SquareButtons.stl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]
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2026-02-01 pcb: button_board: rev 1.6: fix a trace
    [northreach_1_button_board.kicad_pcb]
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

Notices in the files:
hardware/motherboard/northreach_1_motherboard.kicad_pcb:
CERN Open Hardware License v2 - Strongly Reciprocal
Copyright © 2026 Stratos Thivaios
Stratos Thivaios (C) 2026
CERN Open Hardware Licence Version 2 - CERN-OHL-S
